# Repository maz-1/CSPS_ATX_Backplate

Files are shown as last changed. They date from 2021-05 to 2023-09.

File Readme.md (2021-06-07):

# 一个CSPS转ATX电源位的背板，相关项目： [KCORES-CSPS-to-ATX-Converter](https://github.com/KCORES/KCORES-CSPS-to-ATX-Converter)

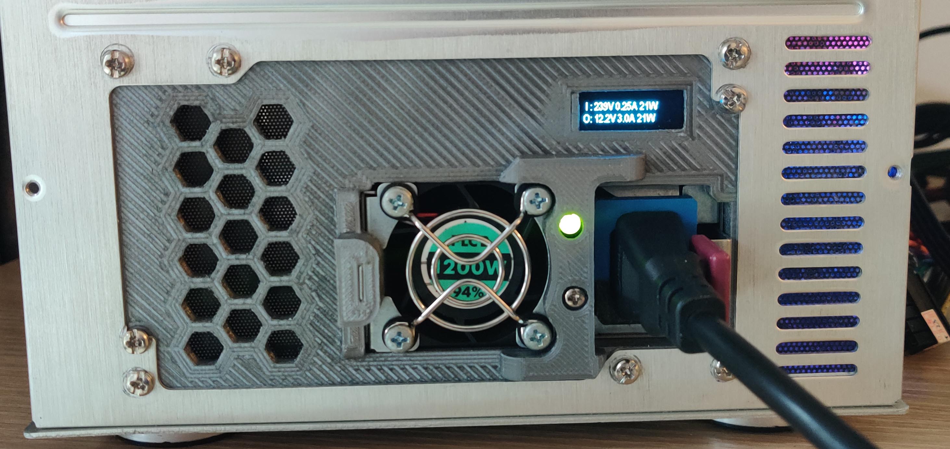
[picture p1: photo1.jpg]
CSPS to ATX Backplate mounted

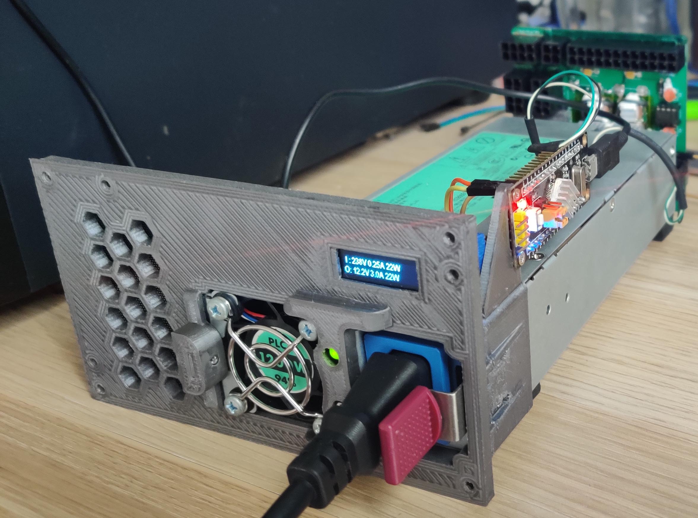
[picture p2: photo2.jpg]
CSPS to ATX Backplate detail1

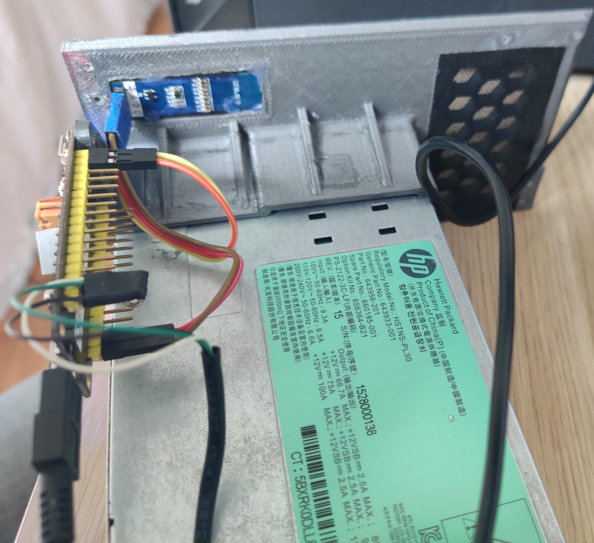
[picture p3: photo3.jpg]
CSPS to ATX Backplate detail2


需要打印的部分 (有条件的用abs/尼龙，petg也可，最好别用pla)：
- 
- STL/csps-atx-mount.stl （背板）
- STL/reinforcement1.stl （固定件一）
- STL/reinforcement2.stl （固定件二）

使用方法：
-
- 卸掉电源把手上的螺丝，把把手拿掉，螺丝备用
- 按住拨片把电源插入，左侧风扇位置金属外壳和背板平行，右侧和限位块接触
- 把固定件一和固定件二放到对应位置，用万能胶固定
- 胶干了以后把把手螺丝拧到固定件螺丝孔位

显示屏为ssd1306驱动的0.91寸128x32分辨率oled屏，用热熔胶固定到对应位置，单片机为stm32f103c8t6。程序及引脚接法见 [KCORES_Link_V1](Arduino/KCORES_Link_V1)

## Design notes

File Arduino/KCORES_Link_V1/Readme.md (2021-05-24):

# 适用于STM32F103C8T6的arduino程序，提供oled显示和串口输出

引脚连接：

 *   PB8  -> CSPS SCL
 *   PB9  -> CSPS SDA
 *   G    -> CSPS GND
 *   PB10 -> 12832 SCL
 *   PB11 -> 12832 SDA
 *   V3   -> 12832 VCC
 *   G    -> 12832 GND

使用VSCode + PlatformIO编译, 编译命令：`platformio run -e bluepill_f103c8`

如果你给STM32F103C8T6安装了hid bootloader, 你可以直接运行`platformio run -e bluepill_f103c8 -t upload`编译并上传

2021/5/24：使用PlatformIO后可以成功兼容CH32F103C8T6。编译完成后需要手动使用WCHISPTool上传，参数如下：

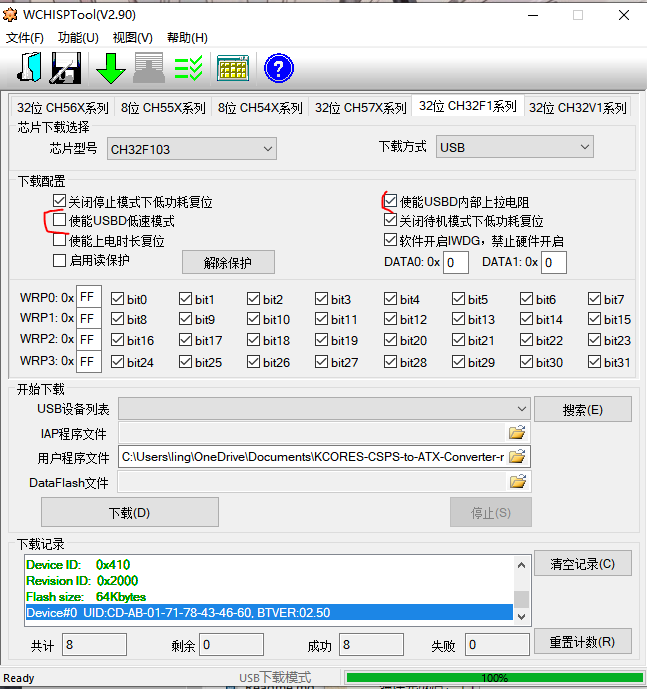
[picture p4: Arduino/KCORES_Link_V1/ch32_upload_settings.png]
ch32_upload_settings


通过usb连接电脑时需要接正面的microusb/typec口（有跳线帽的一侧）

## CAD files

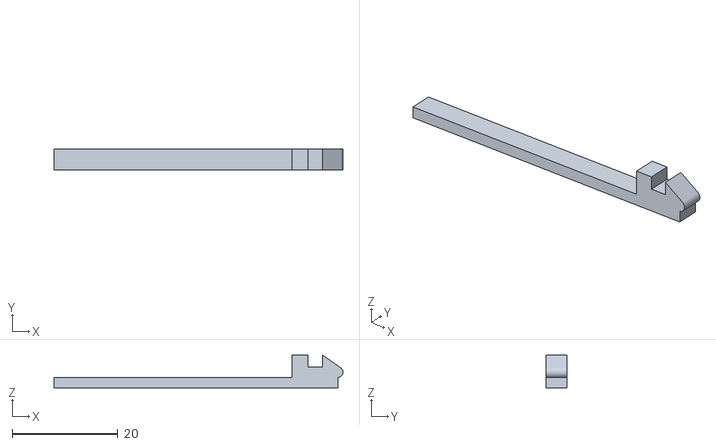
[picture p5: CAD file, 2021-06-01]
STL/clip2.stl
54.8 x 4.00 x 6.25

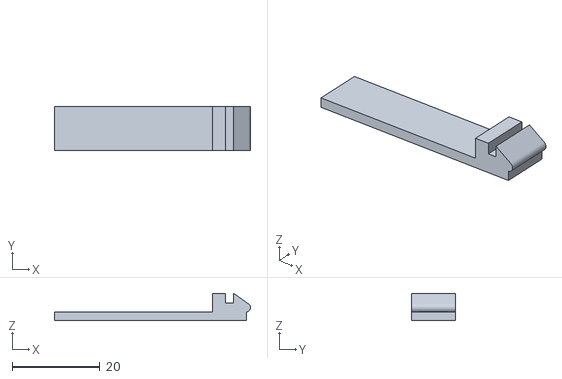
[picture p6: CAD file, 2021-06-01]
STL/clip.stl
44.8 x 10.0 x 6.25

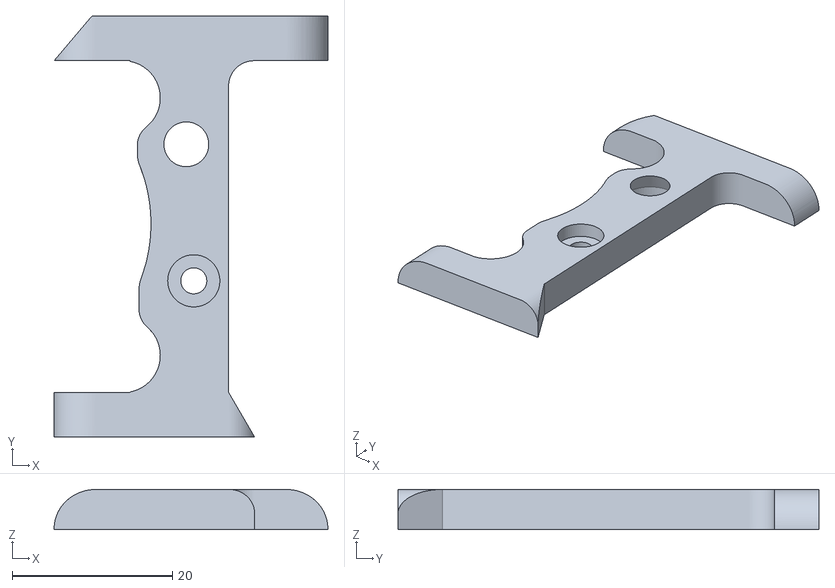
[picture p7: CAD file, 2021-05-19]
STL/reinforcement2.stl
34.2 x 52.5 x 5.00

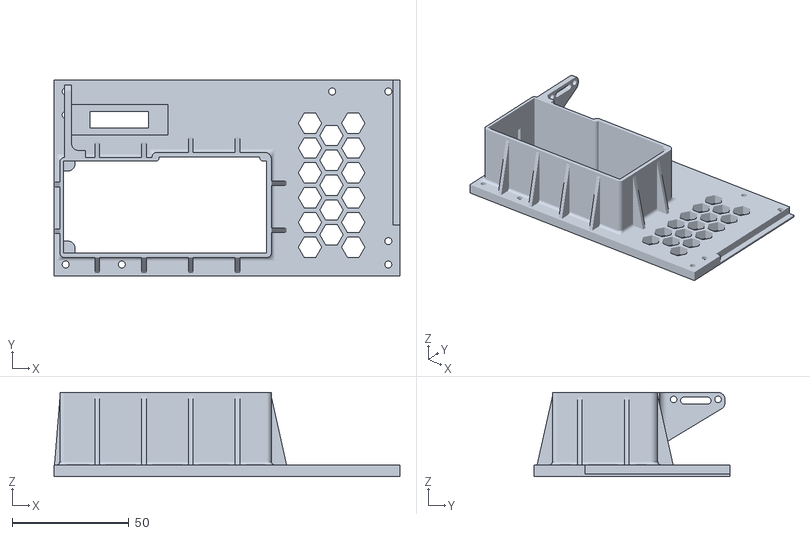
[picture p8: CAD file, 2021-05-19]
STL/csps-atx-mount.stl
148.0 x 84.0 x 36.0

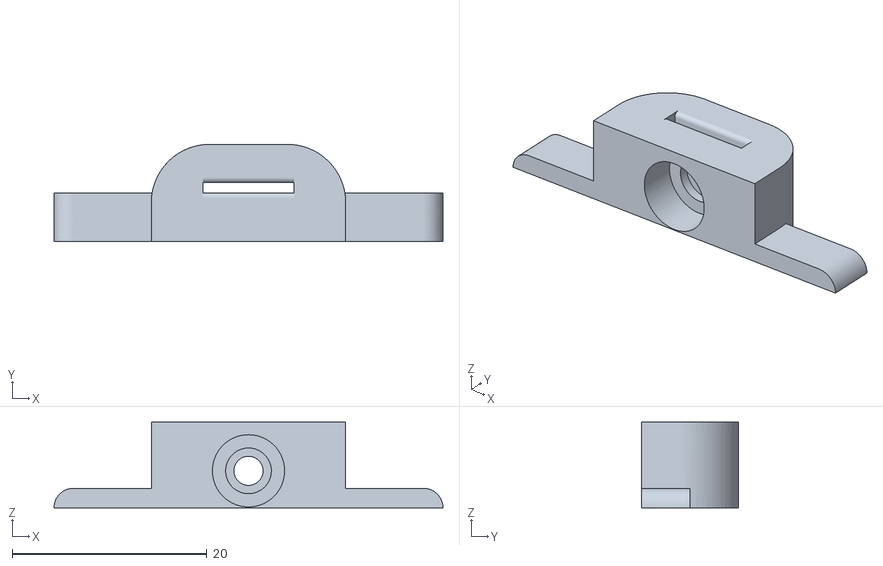
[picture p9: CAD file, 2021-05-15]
STL/reinforcement1.stl
40.0 x 10.0 x 8.80

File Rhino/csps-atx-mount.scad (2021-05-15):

// move & rotate
translate_x=-52;
translate_y=-5;
rotate_z=0;
// space for motherboard
space_for_motherboard=true;

rotate(a=[180,0,0])
union()
{
    difference()
    {
        rotate(a=[0,0,rotate_z])
        translate([translate_x,translate_y,0])
        // plate with screw holes
        difference()
        {
            translate([-5,-5,0])
                cube([148,84,5],center=false);
            union()
            {
                if (space_for_motherboard)
                {
                    translate([-6,17,-3])
                        cube([4,63,7],center=false);
                }
                // atx psu screw holes
                cylinder(h=12, r=1.5, $fn=12, center=true);
                translate([114,0,0])
                    cylinder(h=12, r=1.5, $fn=12, center=true);
                translate([138,0,0])
                    cylinder(h=12, r=1.5, $fn=12, center=true);
                translate([0,10,0])
                    cylinder(h=12, r=1.5, $fn=12, center=true);
                translate([138,64,0])
                    cylinder(h=12, r=1.5, $fn=12, center=true);
                translate([0,74,0])
                    cylinder(h=12, r=1.5, $fn=12, center=true);
                translate([24,74,0])
                    cylinder(h=12, r=1.5, $fn=12, center=true);
                translate([138,74,0])
                    cylinder(h=12, r=1.5, $fn=12, center=true);
            }
        }
        
        translate([0,0,-1])
        difference()
        {
            union()
            {
                translate([3,0,0])
                    cube([43,41,7],center=false);
                cube([87,39.2,7],center=false);
            }
            /*
            union()
            {
                translate([82,0,0])
                    cube([5,5,7],center=false);
                translate([82,35,0])
                    cube([5,5,7],center=false);
            }
            */
        }
    }
    
    union()
    {
        translate([82,0,-1.5])
            cube([5,5,6.5],center=false);
        translate([82,35,-1.5])
            cube([5,5,6.5],center=false);
    }
            
    translate([-2,-2,-31])
        difference()
        {
            cube([90.5,45,36],center=false);
            union()
            {
                translate([5,2,-1])
                    cube([43,41,38],center=false);
                translate([2,2,-1])
                    cube([87,39.2,38],center=false);
                translate([51,42.8,-1])
                    cube([41,4,38],center=false);
                // slots
                translate([88.5,13,13])
                    cube([6,2,10],center=false);
                translate([87.5,27.5,13])
                    cube([6,2,10],center=false);
            }
        }
}

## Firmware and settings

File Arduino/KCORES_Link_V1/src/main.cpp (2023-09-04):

#include "Arduino.h"
/*!
 * Work with KCORES Link V0.0.1 https://github.com/KCORES/kcores-link
 *
 * Written by AlphaArea
 *
 * GPL license, all text here must be included in any redistribution.
 *
 */

/* Modified by maz-1 for stm32f103c8t6 and 0.91 inch 12832 oled display
 * Should be compiled with stm32duino : https://github.com/stm32duino/BoardManagerFiles/raw/master/package_stmicroelectronics_index.json
 * Watch this video about how to install hid bootloader : https://www.youtube.com/watch?v=Myon8H111PQ
 * stm32f103c8t6 should be powered by onboard usb, it will also provide a virtual serial port that can be used by KCORES Link
 * Pin connections:
 *   PB8  -> CSPS SCL
 *   PB9  -> CSPS SDA
 *   G    -> CSPS GND
 *   PB10 -> 12832 SCL
 *   PB11 -> 12832 SDA
 *   V3   -> 12832 VCC
 *   G    -> 12832 GND
 */


#include "KCORES_CSPS.h"


#include <Adafruit_GFX.h>
#include <Adafruit_SSD1306.h>
#include "ArialNarrow7pt7b.h"
//#include "SourceHanMono_Regular7pt7b.h"
#define DEFAULT_FONT ArialNarrow7pt7b
#include "Digital_7pt7b.h"
#include "BitmapFan.h"
#define DATA_UPDATE_INTERVAL 500
#define SCREEN_WIDTH 128 // OLED display width, in pixels
#define SCREEN_HEIGHT 64 // OLED display height, in pixels
// SDA SCL
TwoWire WireOLED(PB11, PB10);
#define OLED_RESET     4 // Reset pin # (or -1 if sharing Arduino reset pin)
#define SCREEN_ADDRESS 0x3C ///< See datasheet for Address; 0x3D for 128x64, 0x3C for 128x32
Adafruit_SSD1306 display(SCREEN_WIDTH, SCREEN_HEIGHT, &WireOLED, OLED_RESET);
String OutputOLEDString;

CSPS PowerSupply_1(0x5F, 0x57, PB9, PB8);

float VoltIn, VoltOut,
    CurrentIn, CurrentOut,
    PowerIn, PowerOut,
    Temp1,
    Temp2,
    FanSpeed;
float Efficiency;
bool PowerGood;
bool PowerGoodOled;

String OutputString;
uint8_t OutputLen = 0;

bool displayInitialized;

const float animation_update_intervals[] = {500, 250, 166.66, 125, 100, 83.33, 71.43, 62.5, 55.55, 50};
const int animation_update_intervals_len = 10;
const float fan_speed_lbound = 500;
const float fan_speed_hbound = 10000;
const float fan_speed_range = 9500;
int animation_frame = 0;
int animation_update_interval_idx = 0;
float data_update_timestamp = 0;

void update_oled_pg(bool force)
{
  if (PowerGoodOled == PowerGood && !force)
  {
    return;
  }
  display.setFont(&DEFAULT_FONT);
  if (PowerGood)
  {
    display.fillRoundRect(92, 0, 32, 14, 4, SSD1306_WHITE);
    display.setTextColor(SSD1306_BLACK);
    display.setCursor(99, 11);
    display.print("ON");
  }
  else
  {
    display.fillRect(92, 0, 32, 14, SSD1306_BLACK);
    display.drawRoundRect(92, 0, 32, 14, 4, SSD1306_WHITE);
    display.setTextColor(SSD1306_WHITE);
    display.setCursor(96, 11);
    display.print("OFF");
  }
  PowerGoodOled = PowerGood;
}

void setup()
{
  Serial.begin(115200);
  Wire.setClock(100000);

  displayInitialized = false;
  //display.setFont(&SourceHanMono_Regular7pt7b);
  //display.setFont(&FreeMono9pt7b);
  // SSD1306_SWITCHCAPVCC = generate display voltage from 3.3V internally
  if(display.begin(SSD1306_SWITCHCAPVCC, SCREEN_ADDRESS)) {
    // https://github.com/olikraus/u8g2/issues/1806
    // https://www.buydisplay.com/download/ic/SSD1312_Datasheet.pdf Pg. 51 Section 2.1.19
    //            normal    inverted
    // normal     A1 C8       A0 C0
    // mirrored   A0 C8       A1 C0
    // combination1: A0 C8
    // combination2: A1 C0
    display.ssd1306_command(0xA1);
    display.ssd1306_command(0xC0);
    displayInitialized = true;
  } else {
    //Serial.println(F("SSD1306 allocation failed"));
  }
  
  if (displayInitialized)
  {
    display.setTextSize(1);      // pixel scale
    //display.setTextColor(SSD1306_WHITE); // Draw white text
    display.cp437(true);         // Use full 256 char 'Code Page 437' font
    //display.setRotation(2);      // rotate screen
    
    display.clearDisplay();
    // fixed content
    // header
    display.fillRect(0, 0, 80, 16, SSD1306_WHITE);
    // vlines
    display.drawLine(0, 0, 0, 64, SSD1306_WHITE);
    display.drawLine(40, 0, 40, 16, SSD1306_BLACK);
    display.drawLine(40, 16, 40, 47, SSD1306_WHITE);
    display.drawLine(80, 0, 80, 64, SSD1306_WHITE);
    // hlines
    display.drawLine(0, 47, 80, 47, SSD1306_WHITE);
    display.drawLine(0, 63, 80, 63, SSD1306_WHITE);
    // header text
    display.setTextColor(SSD1306_BLACK);
    display.setFont(&DEFAULT_FONT);
    display.setCursor(10, 12);     // Start at top-left corner
    display.print("AC");
    display.setCursor(50, 12);
    display.print("DC");
    // unit
    display.setTextColor(SSD1306_WHITE);
    display.setCursor(31, 28);
    display.print("V");
    display.setCursor(31, 42);
    display.print("A");
    display.setCursor(71, 28);
    display.print("V");
    display.setCursor(71, 42);
    display.print("A");
    display.setCursor(20, 60);
    display.print("%");
    display.setCursor(70, 60);
    display.print("W");
    // pg
    update_oled_pg(true);
  }
  
}

void get_csps_values()
{
  VoltIn = PowerSupply_1.getInputVoltage();
  VoltOut = PowerSupply_1.getOutputVoltage();
  CurrentIn = PowerSupply_1.getInputCurrent();
  CurrentOut = PowerSupply_1.getOutputCurrent();
  PowerIn = PowerSupply_1.getInputPower();
  PowerOut = PowerSupply_1.getOutputPower();
  Temp1 = PowerSupply_1.getTemp1();
  Temp2 = PowerSupply_1.getTemp2();
  FanSpeed = PowerSupply_1.getFanRPM();
  Efficiency = PowerOut * 100 / PowerIn;
  // FIXME: should be decided by PowerSupply_1.getFlags()
  PowerGood = true;
}

void test_csps_values()
{
  VoltIn = 226.23;
  VoltOut = 12.21;
  CurrentIn = 6.11;
  CurrentOut = 106.01;
  PowerIn = 1347.2;
  PowerOut = 1293.3;
  //Temp1 = PowerSupply_1.getTemp1();
  //Temp2 = PowerSupply_1.getTemp2();
  FanSpeed = 7000;
  Efficiency = PowerOut * 100 / PowerIn;
  PowerGood = true;
}

void print_to_serial()
{
  Serial.print(" ");
  OutputLen = 0;
  OutputString = String(VoltIn, 1) + ',' + String(CurrentIn, 2) + ',' + String(PowerIn, 1) + ',';
  OutputLen += OutputString.length();
  Serial.print(OutputString);

  OutputString = String(VoltOut, 2) + ',' + String(CurrentOut, 2) + ',' + String(PowerOut, 1) + ',';
  OutputLen += OutputString.length();
  Serial.print(OutputString);

  OutputString = String(Temp1, 1) + ',' + String(Temp2, 1) + ',' + String(FanSpeed, 0) + ',';
  OutputLen += OutputString.length();
  Serial.print(OutputString);
  Serial.print(",,");

  OutputLen = 59 - OutputLen;

  for (; OutputLen > 0; OutputLen--)
    Serial.print(" ");

  Serial.print("\n");
}

uint32_t digits10(uint64_t v) {
    if (v < 10) return 1;
    if (v < 100) return 2;
    if (v < 1000) return 3;
    if (v < 1000000000000) {    // 10^12
        if (v < 100000000) {    // 10^8
            if (v < 1000000) {  // 10^6
                if (v < 10000) return 4;
                return 5 + (v >= 100000); // 10^5
            }
            return 7 + (v >= 10000000); // 10^7
        }
        if (v < 10000000000) {  // 10^10
            return 9 + (v >= 1000000000); // 10^9
        }
        return 11 + (v >= 100000000000); // 10^11
    }
    return 12 + digits10(v / 1000000000000); // 10^12
}

void update_oled_values()
{
  // dynamic data
  display.setTextColor(SSD1306_WHITE);
  display.setFont(&Digital_7pt7b);
  // AC info
  display.fillRect(1, 16, 30, 31, SSD1306_BLACK);
  display.setCursor(2, 30);
  display.print(String(VoltIn, 0));
  display.setCursor(2, 44);
  if (CurrentIn >= 10)
    display.print(String(CurrentIn, 1));
  else
    display.print(String(CurrentIn, 2));
  // DC info
  display.fillRect(41, 16, 30, 31, SSD1306_BLACK);
  display.setCursor(42, 30);
  display.print(String(VoltOut, 1));
  display.setCursor(42, 44);
  if (CurrentOut >= 100)
    display.print(String(CurrentOut, 0));
  else
    display.print(String(CurrentOut, 1));
  // PWR info
  display.setCursor(2, 61);
  display.print(String(Efficiency, 0));
  display.fillRect(35, 48, 34, 13, SSD1306_BLACK);
  // display.setCursor(35, 61);
  display.setCursor(67 - 8*digits10((int)PowerOut), 61);
  display.print(String(PowerOut, 0));
  // Fan info
  display.fillRect(81, 48, 48, 13, SSD1306_BLACK);
  //display.setCursor(81, 61);
  display.setCursor(105-(digits10((int)FanSpeed)+1)*8/2, 61);
  display.print(String(FanSpeed, 0)+ "R");
  // On/Off
  update_oled_pg(false);
}

void update_oled_animation_frame()
{
  display.fillRect(92, 16, 32, 32, SSD1306_BLACK);
  display.drawBitmap(92, 16, fan_bitmap_allArray[animation_frame], 32, 32, SSD1306_WHITE);
  if (animation_frame)
    animation_frame = 0;
  else
    animation_frame = 1;
}

void loop()
{
  if (data_update_timestamp == 0)
  {
    //get_csps_values();
    test_csps_values();
    // update animation speed
    if (FanSpeed <= fan_speed_lbound)
    {
      animation_update_interval_idx = 0;
    }
    else if (FanSpeed >= fan_speed_hbound)
    {
      animation_update_interval_idx = 9;
    }
    else
    {
      animation_update_interval_idx = floor((FanSpeed - fan_speed_lbound) * 10.0 / fan_speed_range);
    }
  }

  if (data_update_timestamp == 0)
  {
    print_to_serial();
  }

 
  if (displayInitialized)
  {
    if (data_update_timestamp == 0)
    {
      update_oled_values();
    }
    // Fan anim
    update_oled_animation_frame();
      
    display.display();
  }

  data_update_timestamp += animation_update_intervals[animation_update_interval_idx];
  if (abs(DATA_UPDATE_INTERVAL-data_update_timestamp) < 10)
    data_update_timestamp = 0;
  delay((int)animation_update_intervals[animation_update_interval_idx]);
}

void serialEvent()
{
  PowerSupply_1.setFanRPM(Serial.readStringUntil('\n').toInt());
}

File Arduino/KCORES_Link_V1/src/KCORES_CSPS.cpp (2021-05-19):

/*!
 * @file KCORES_CSPS.cpp
 *
 * This is a library for the CSPS PMBUS
 * Written by AlphaArea
 *
 * GPL license, all text here must be included in any redistribution.
 *
 */

#include "KCORES_CSPS.h"

// avoid PB7 PB6 
// SDA SCL
//TwoWire Wire2(PB11,PB10);

#define WIRE Wire

CSPS::CSPS(byte CSPS_addr, uint8_t sda, uint8_t scl)
{
  _CSPS_addr = CSPS_addr;
  _ROM_addr = CSPS_addr - 8;
  WIRE.setSDA(sda);
  WIRE.setSCL(scl);
  WIRE.begin();
}

CSPS::CSPS(byte CSPS_addr, byte ROM_addr, uint8_t sda, uint8_t scl)
{
  _CSPS_addr = CSPS_addr;
  _ROM_addr = ROM_addr;
  WIRE.setSDA(sda);
  WIRE.setSCL(scl);
  WIRE.begin();
}

String CSPS::getROM(byte addr, byte len)
{
  String rec;
  for (byte n = 0; n < len; n++)
    rec.concat((char)readROM(addr + n));
  return rec;
}

byte CSPS::readROM(byte dataAddr)
{
  byte rec = 0x00;
  WIRE.beginTransmission(_ROM_addr);
  WIRE.write(dataAddr);
  WIRE.endTransmission();
  WIRE.requestFrom(_ROM_addr, 1);
  if (WIRE.available())
    rec = WIRE.read();
  return rec;
}


uint32_t CSPS::readCSPSword(byte dataAddr)
{
  byte regCS = ((0xFF - (dataAddr + (_CSPS_addr << 1))) + 1) & 0xFF;
  uint32_t rec = 0xFFFF;
  WIRE.beginTransmission(_CSPS_addr);
  WIRE.write(dataAddr);
  WIRE.write(regCS);
  WIRE.endTransmission();
  WIRE.requestFrom(_CSPS_addr, 3);
  if (WIRE.available())
  {
    rec = WIRE.read();
    rec |= WIRE.read() << 8;
    //rec |= WIRE.read() << 16;
    return rec;
  }
  else
    return 0;
}

void CSPS::writeCSPSword(byte dataAddr, unsigned int data)
{
  byte valLSB = lowByte(data),
       valMSB = highByte(data);
  uint8_t cs = (_CSPS_addr << 1) + dataAddr + valLSB + valMSB;
  uint8_t regCS = ((0xFF - cs) + 1) & 0xff;
  //the checksum is the 'secret sauce'
  //writeInts = [reg, valLSB, valMSB, regCS]; //write these 4 bytes to i2c
  WIRE.beginTransmission(_CSPS_addr);
  WIRE.write(dataAddr);
  WIRE.write(valLSB);
  WIRE.write(valMSB);
  WIRE.write(regCS);
  WIRE.endTransmission();
}
